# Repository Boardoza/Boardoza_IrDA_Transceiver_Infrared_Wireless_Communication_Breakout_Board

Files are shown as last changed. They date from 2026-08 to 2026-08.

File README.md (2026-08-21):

# Boardoza IrDA Transceiver Breakout Board

The **Boardoza IrDA Transceiver** is a compact infrared communication breakout board designed for reliable short-range wireless data transfer using modulated infrared light. The board integrates both an infrared transmitter and a demodulating infrared receiver, enabling digital data transmission and reception through a simple TXD/RXD interface. It supports operation with both **3.3V and 5V systems**, making it compatible with a wide range of microcontroller platforms.

The onboard hardware-driven LED indicators provide instant visual feedback for power, transmission, and reception activities, making debugging and communication monitoring extremely convenient during development. With its compact footprint and integrated infrared communication circuitry, this board is ideal for **embedded wireless links, short-range wireless control systems, educational electronics projects, robotics, and custom infrared serial communication applications**.

## [Click here to purchase!](https://www.ozdisan.com/ureticiler/boardoza)

| Front Side | Back Side |
|:---:|:---:|
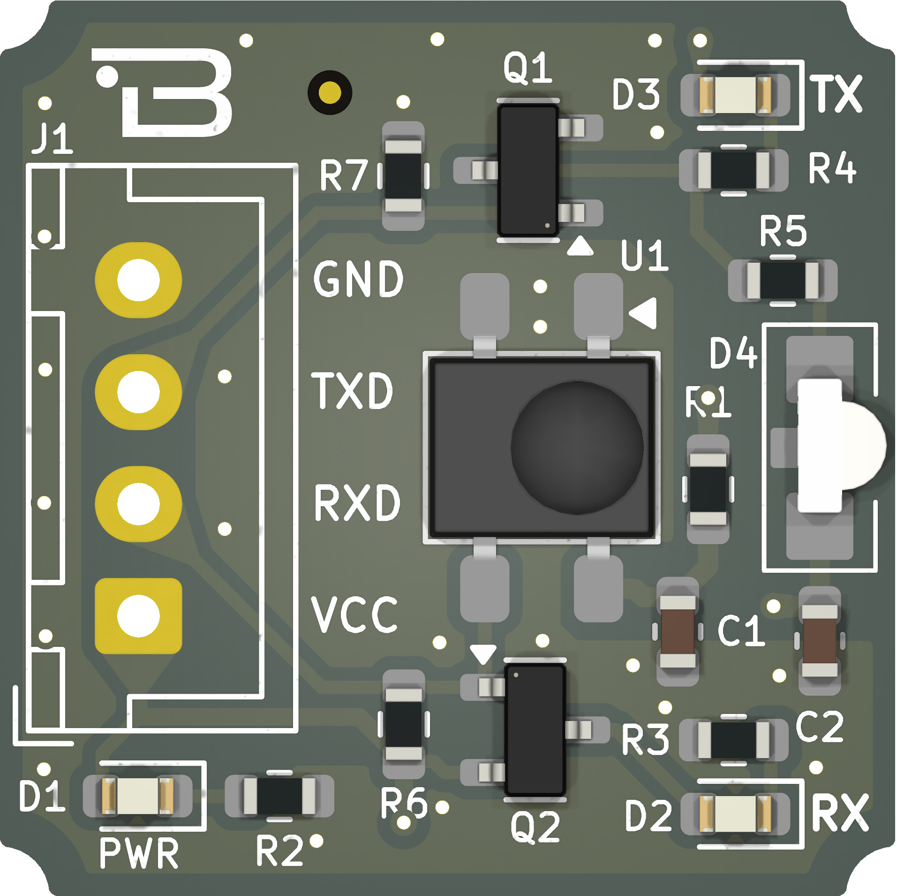
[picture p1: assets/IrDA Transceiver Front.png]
Boardoza IrDA Transceiver Front
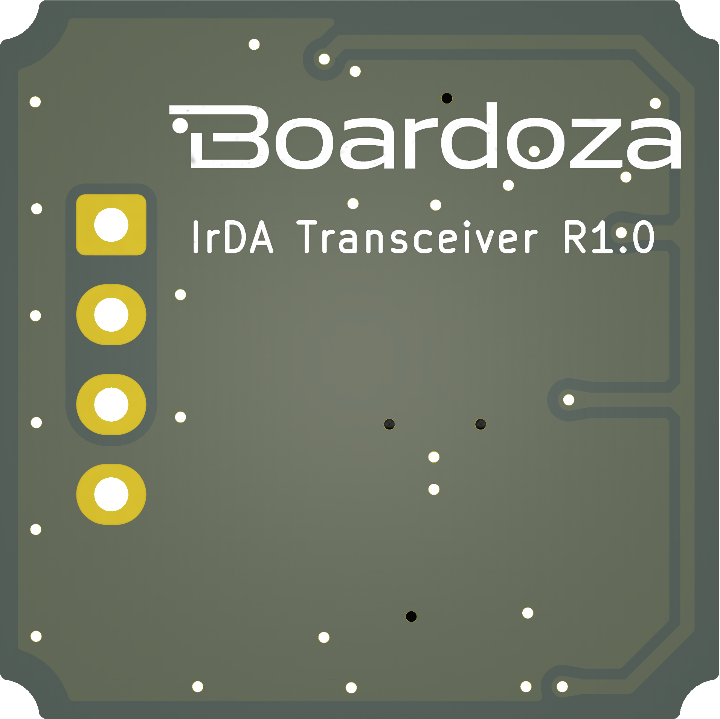
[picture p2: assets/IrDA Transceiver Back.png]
Boardoza IrDA Transceiver Back
|  |  |

---

## Key Features

- **38 kHz Infrared Communication:** Supports reliable infrared wireless data transfer using a 38 kHz modulated carrier frequency.
- **Integrated IR Receiver Circuit:** Features a built-in demodulating infrared receiver for clean and stable digital signal output.
- **Wide Voltage Compatibility:** Operates seamlessly with both 3.3V and 5V microcontroller platforms.
- **Real-Time Status Indicators:** Dedicated hardware LEDs provide instant visual feedback for data reception (D2) and data transmission (D3) activity.  
- **Simple Digital TXD/RXD Interface:** Provides straightforward MCU communication through TXD input and RXD output pins.
- **TX Echo Functionality:** Transmitted data is internally echoed to the RX output for easier debugging and monitoring.

---

## Technical Specifications

**Model:** IrDA Transceiver   
**Manufactorer:** Boardoza  
**Functions:** Infrared Data Transmitter & Receiver  
**Input Voltage:** 3.3V – 5V  
**Communication Type:** Asynchronous Serial  
**Carrier Frequency:** 38 kHz  
**Maximum Data Rate:** Up to 1250 bps  
**Infrared LED Wavelength:** 940 nm  
**Transmission Range (3.3V):** Up to 430 cm  
**Transmission Range (5V):** Up to 600 cm  
**Indicator LEDs:** RX (Yellow), TX (Green)  
**Receiver Type:** Demodulating IR Receiver Module  
**Operating Temperature:** -40°C to +85°C  
**Board Dimensions:** 20mm x 20mm  

> Warning: The TXD pin directly controls the IR transmitter stage and must only be driven with short data pulses. Applying a continuous HIGH level to TXD may cause excessive current through the IR LED/driver circuit and can permanently damage the board.

---

## Board Pinout

### ( J1 ) Communication Connector

| Pin Number | Pin Name | Description |
|:---:|:---:|---|
| 1 | VCC | Power Supply Input |
| 2 | RXD | Data Receive Output |
| 3 | TXD | Data Transmit Input |
| 4 | GND | Ground |

---

## Board Dimensions

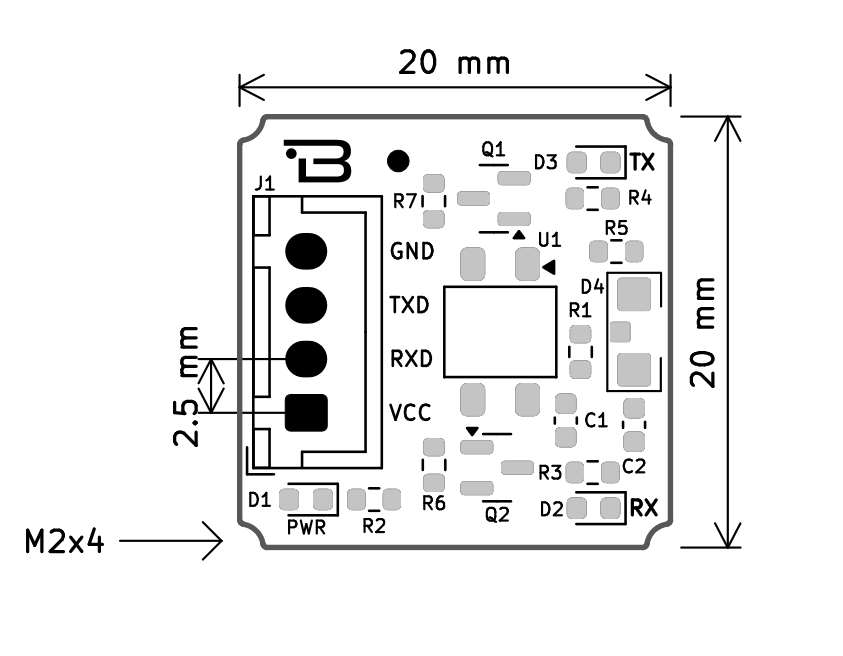
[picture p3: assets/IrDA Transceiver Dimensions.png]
Board Dimensions


---

## Step Files

[Boardoza IrDA Transceiver.step](./assets/IrDA%20Transceiver%20Step.step)

---

## Datasheet

[VSMB10940 Datasheet.pdf](./assets/VSMB10940%20Datasheet.pdf)

[IR Receiver Module Datasheet.pdf](./assets/DMO-0000008%20Datasheet.pdf)

---

## Version History

- V1.0.0 - Initial Release

---

## Support

- If you have any questions or need support, please contact support@boardoza.com

---

## **License**

This repository contains both hardware and software components:

### **Hardware Design**

[][cc-by-sa]

All hardware design files are licensed under [Creative Commons Attribution-ShareAlike 4.0 International License][cc-by-sa].

[cc-by-sa]: http://creativecommons.org/licenses/by-sa/4.0/
[cc-by-sa-shield]: https://img.shields.io/badge/License-CC%20BY--SA%204.0-lightgrey.svg

### **Software/Firmware**

[][bsd]

All software and firmware are licensed under [BSD 3-Clause License][bsd].

[bsd]: https://opensource.org/licenses/BSD-3-Clause
[bsd-shield]: https://img.shields.io/badge/License-BSD%203--Clause-blue.svg

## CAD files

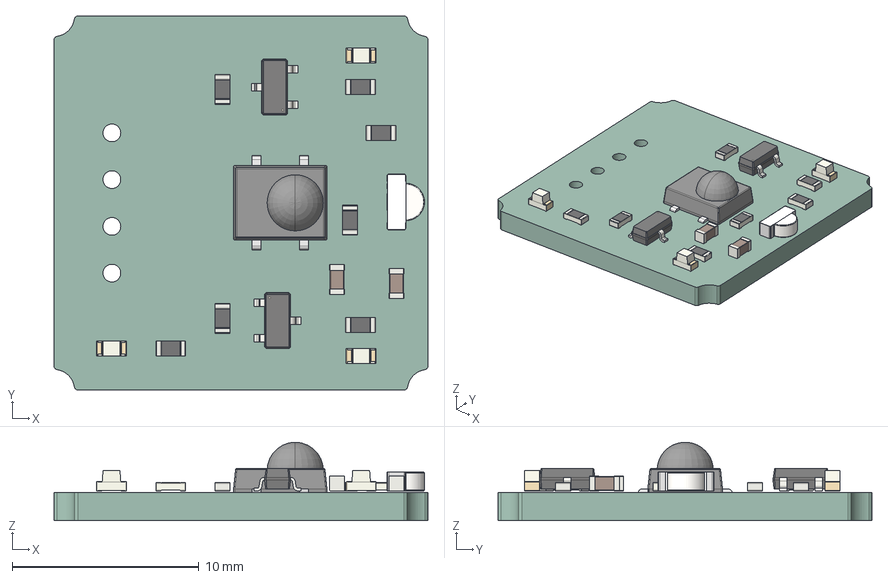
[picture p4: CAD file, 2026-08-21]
assets/IrDA Transceiver Step.step
20.0 x 20.0 x 4.20 mm
SOT-23 x 2
LED_0603_1608Metric x 3
kicad_embedded_3F63F6163099B905C17F5F73C1ED6503
C_0603_1608Metric x 2
R_0603_1608Metric x 7
1^Vishay_-_VSMB10940.step
2^Vishay_-_VSMB10940.step
3^Vishay_-_VSMB10940.step
4.step
5^Vishay_-_VSMB10940.step
kibot_wx7wcv_h_PCB

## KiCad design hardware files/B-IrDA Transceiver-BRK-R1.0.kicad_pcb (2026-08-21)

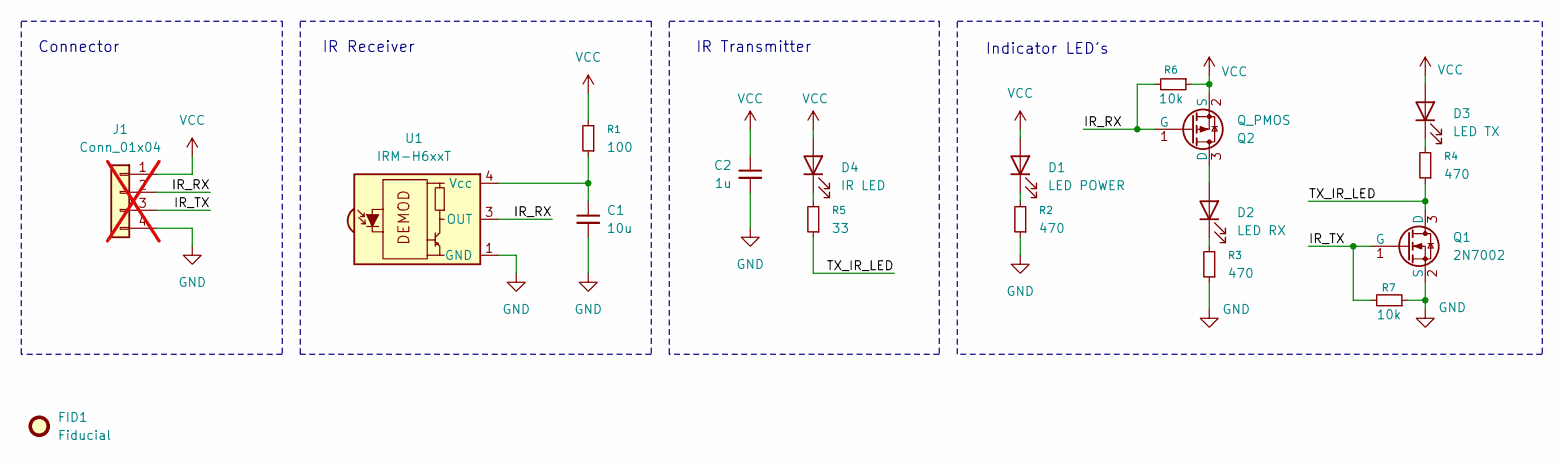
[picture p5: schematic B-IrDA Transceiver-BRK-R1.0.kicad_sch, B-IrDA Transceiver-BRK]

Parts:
C1: 10u; C_0603_1608Metric; MPN CL10A106KQ8NNNC
C2: 1u; C_0603_1608Metric; MPN CL10B105KO8NNNC
D1: LED POWER; LED_0603_1608Metric; MPN LTST-C191KRKT
D2: LED RX; LED_0603_1608Metric; MPN LTST-C191KSKT
D3: LED TX; LED_0603_1608Metric; MPN LTST-C191KGKT
D4: IR LED; VSMB10940; MPN VSMB10940
FID1: Fiducial; Fiducial_0.5mm_Mask1mm
J1: Conn_01x04; JST_XH_B4B-XH-A_1x04_P2.50mm_Vertical; MPN L-KLS1-2.50-04-SB; not fitted
Q1: 2N7002; SOT-23; MPN 2N7002_R1_00001
Q2: Q_PMOS; SOT-23; MPN BSS84-HT
R1: 100; R_0603_1608Metric; MPN 0603SAJ0101T5E
R2, R3, R4: 470; R_0603_1608Metric; MPN 0603SAJ0471T5E
R5: 33; R_0603_1608Metric; MPN 0603SAJ0330T5E
R6, R7: 10k; R_0603_1608Metric; MPN 0603SAJ0103T5E
U1: IRM-H6xxT; Everlight_IRM-H6xxT; MPN IRM-H638T/TR2

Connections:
/IR_RX: J1.2, Q2.1 (G), R6.2, U1.3 (OUT)
/IR_TX: J1.3, Q1.1 (G), R7.2
/TX_IR_LED: Q1.3 (D), R4.1, R5.1
GND: C1.2, C2.2, J1.4, Q1.2 (S), R2.1, R3.1, R7.1, U1.1 (GND), U1.2 (GND)
unnamed: D1.1 (K), R2.2
unnamed: D2.2 (A), Q2.3 (D)
unnamed: D2.1 (K), R3.2
unnamed: D3.1 (K), R4.2
unnamed: D4.1 (K), R5.2
unnamed: C1.1, R1.1, U1.4 (Vcc)
VCC: C2.1, D1.2 (A), D3.2 (A), D4.2 (A), J1.1, Q2.2 (S), R1.2, R6.1

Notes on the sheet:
IR Receiver
Indicator LED's
Connector
IR Transmitter

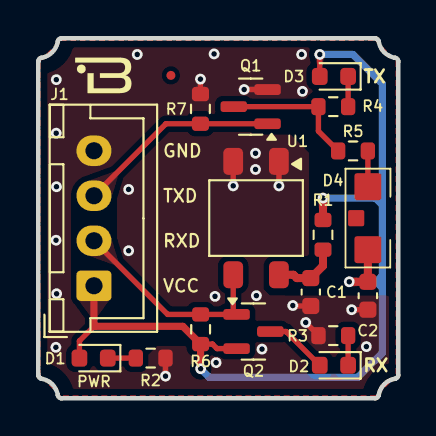
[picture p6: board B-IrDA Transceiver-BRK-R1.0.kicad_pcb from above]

Board: 2 copper layers, 20.0 x 20.0 mm, 18 parts (0 on the bottom side), 11 nets.

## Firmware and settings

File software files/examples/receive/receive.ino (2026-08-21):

#include <Arduino.h>

// --- SETTINGS ---
const int IR_RX_PIN = 2; // IR Receiver OUT/DATA pin

// Variable to track the last known state
int lastState = -1; 

void setup() {
    // Enable internal pull-up resistor for stability
    pinMode(IR_RX_PIN, INPUT_PULLUP);
    
    Serial.begin(115200);
    delay(1000); // Startup safety
    
    Serial.println("--- IR Receiver Mode Started ---");
    Serial.println("Waiting for signal (1 = Signal, 0 = No Signal)...");
    Serial.println("--------------------------------------------------");
}

void loop() {
    // Read the raw pin state
    // Standard IR receivers output LOW when receiving a 38kHz signal
    int rawState = digitalRead(IR_RX_PIN);
    
    // Convert logic: 1 for Signal Present, 0 for No Signal
    int signalPresent = (rawState == LOW) ? 1 : 0;

    // Only print if the state has changed to prevent Serial Monitor spam
    if (signalPresent != lastState) {
        Serial.println(signalPresent);
        
        // Update the last state
        lastState = signalPresent;
    }
    
    // Small delay to prevent processor overload
    delay(1);
}

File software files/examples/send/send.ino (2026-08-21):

#include <Arduino.h>

// --- SETTINGS ---
const int IR_TX_PIN = 1; // Safe GPIO pin (do not use 10!)

// Timing Settings
const int CARRIER_FREQ_KHZ = 38;    // 38 kHz Carrier
const int PACKET_RATE_HZ   = 10;    // 10 packets per second rate (10 Hz)
const int BURST_COUNT      = 8;     // Number of packets to send at once (8 times)
const int LONG_WAIT_MS     = 1000;  // Wait time at end of loop (1 second)

// Calculated Values (Automatic)
const int PACKET_PERIOD_MS = 1000 / PACKET_RATE_HZ; // 100 ms period
const int BURST_DURATION_MS = PACKET_PERIOD_MS / 2; // 50% duty cycle (50 ms Signal)

// --- HELPER FUNCTION: Outputs 38 kHz Signal ---
void transmit38kHz(int duration_ms) {
    // For 38 kHz, period ~26 µs (13 µs High / 13 µs Low)
    unsigned long startTime = millis();
    
    while (millis() - startTime < duration_ms) {
        digitalWrite(IR_TX_PIN, HIGH);
        delayMicroseconds(13); 
        digitalWrite(IR_TX_PIN, LOW);
        delayMicroseconds(13);
    }
}

void setup() {
    pinMode(IR_TX_PIN, OUTPUT);
    Serial.begin(115200);
    delay(1000); // Startup safety
    
    Serial.println("--- IR Test Mode Started ---");
    Serial.printf("Speed: %d Hz (Each packet %d ms)\n", PACKET_RATE_HZ, PACKET_PERIOD_MS);
    Serial.printf("Packet Count: %d items\n", BURST_COUNT);
    Serial.println("-------------------------------");
}

void loop() {
    Serial.println("Sending Signal Packet... (8 x High)");

    // 1. Send signal as many times as requested (8 times)
    for (int i = 0; i < BURST_COUNT; i++) {
        unsigned long packetStart = millis();

        // A) Signal Part (38 kHz Carrier Present) - Ex: 50 ms
        transmit38kHz(BURST_DURATION_MS); 

        // B) Silence Part (No Carrier) - Complete the period
        digitalWrite(IR_TX_PIN, LOW);
        
        // Wait for the rest of the 100 ms period
        while (millis() - packetStart < PACKET_PERIOD_MS) {
            // Empty wait (delay can be used instead of busy wait but this is more precise)
            delay(1); 
        }
    }

    // 2. Long Wait (1 Second)
    Serial.println("Waiting... (1 sec)");
    delay(LONG_WAIT_MS);
}

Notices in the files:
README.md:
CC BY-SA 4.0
